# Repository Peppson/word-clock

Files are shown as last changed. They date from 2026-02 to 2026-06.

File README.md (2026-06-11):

# WordClock   

> **Note:** This is a personal hobby project.  

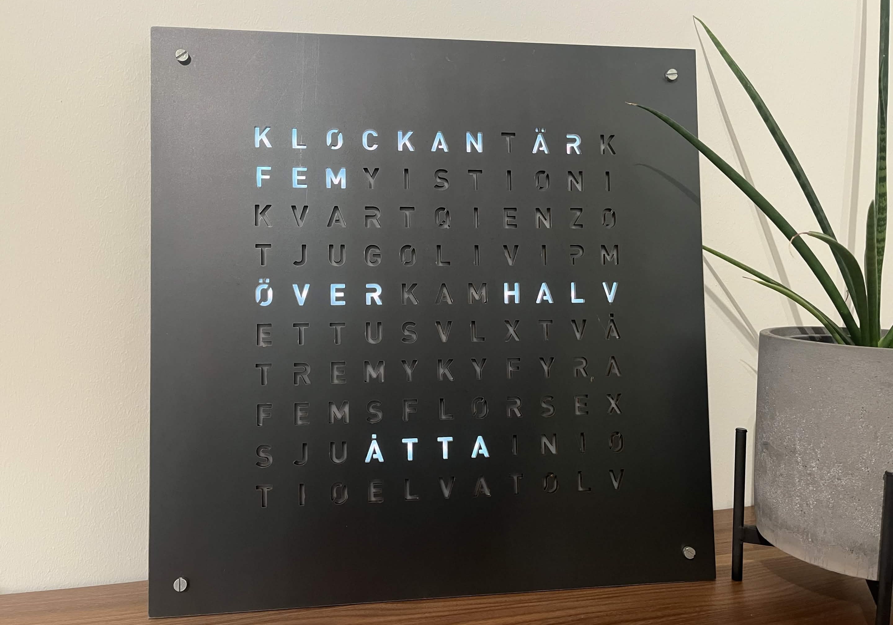
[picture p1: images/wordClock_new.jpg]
wordClock
 

## Overview
- Machine-cut 45x45cm metal faceplate *(Swedish time notation)*
- Web Interface for configuration and playing games on the 11x10 grid! 
- Wi-Fi time synchronization with optional manual time setting
- Ambient light sensor for automatic brightness control
- Physical buttons for direct control
- NeoPixel LEDs with full RGB color

## Web Interface
A simple accesspoint that is activated using a physical button.
- Configure Wi-Fi credentials for NTP time synchronization
- Manually set the time *(alternative to NTP)*
- Adjust LED colors
- Play Snake *(why not?)*

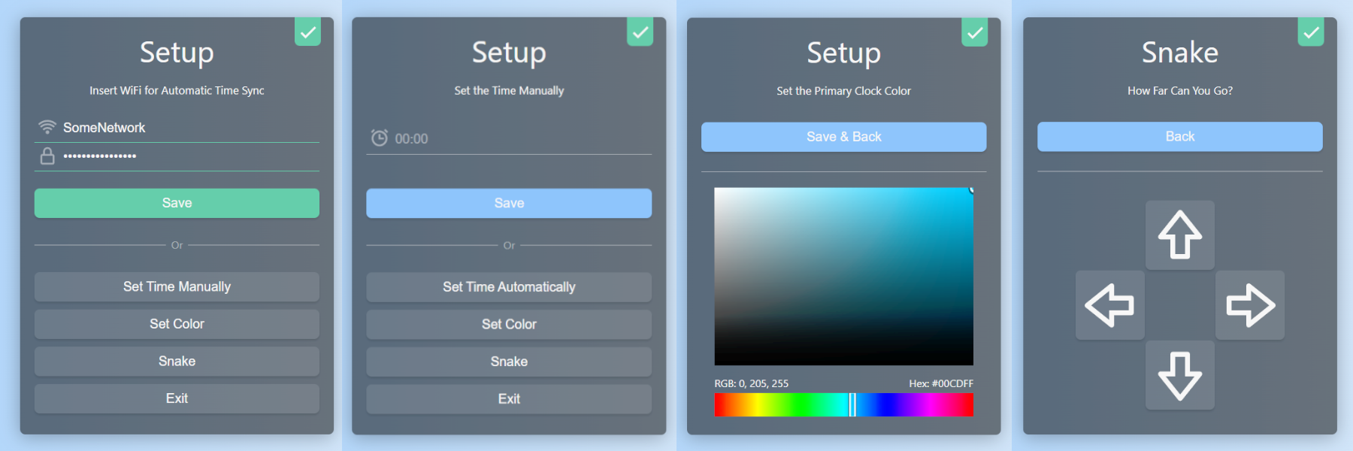
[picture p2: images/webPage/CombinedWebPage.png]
webPage
 

## Hardware/Build

#### Parts used:
- ESP32 microcontroller
- WS2812B (NeoPixel) LEDs ×110
- TSL2591 lux sensor
- Basic electronic components

Schematic:
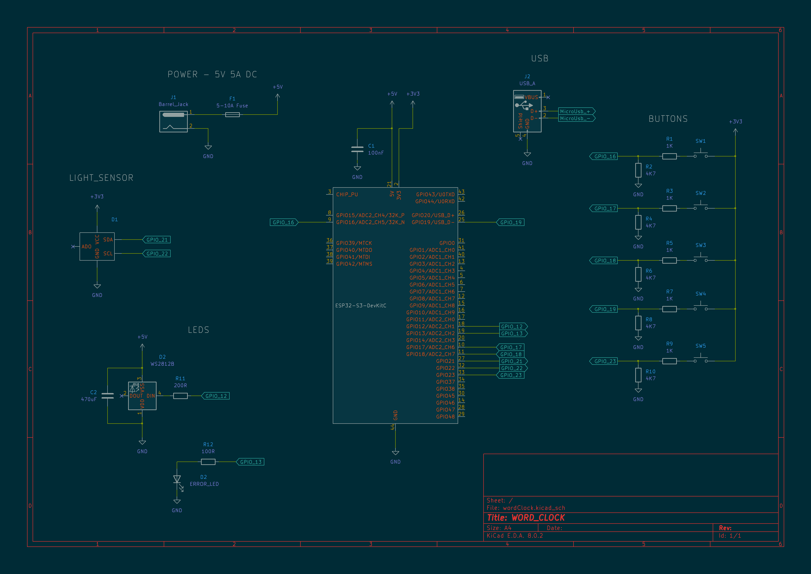
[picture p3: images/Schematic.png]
Schematic
 

Cross section *(thanks Chat)*
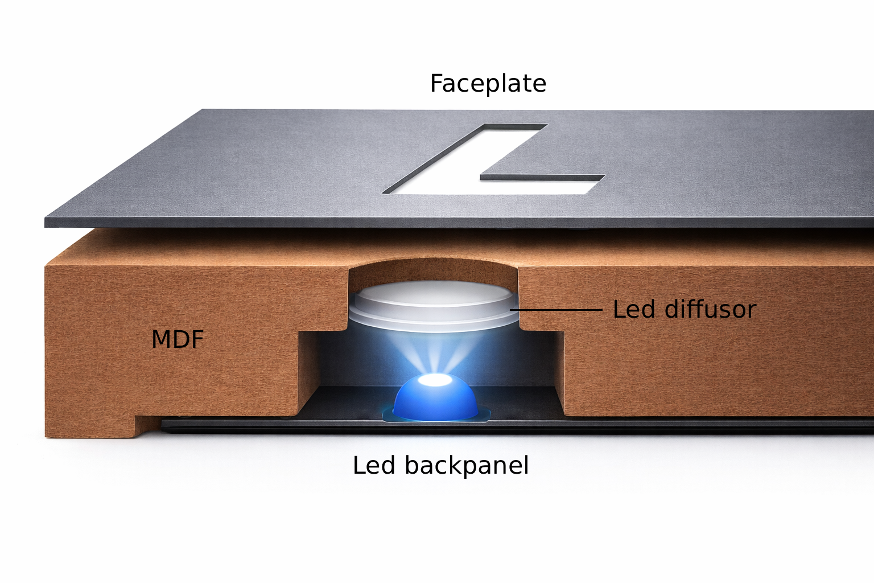
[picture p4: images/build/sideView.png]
 

MDF backside:
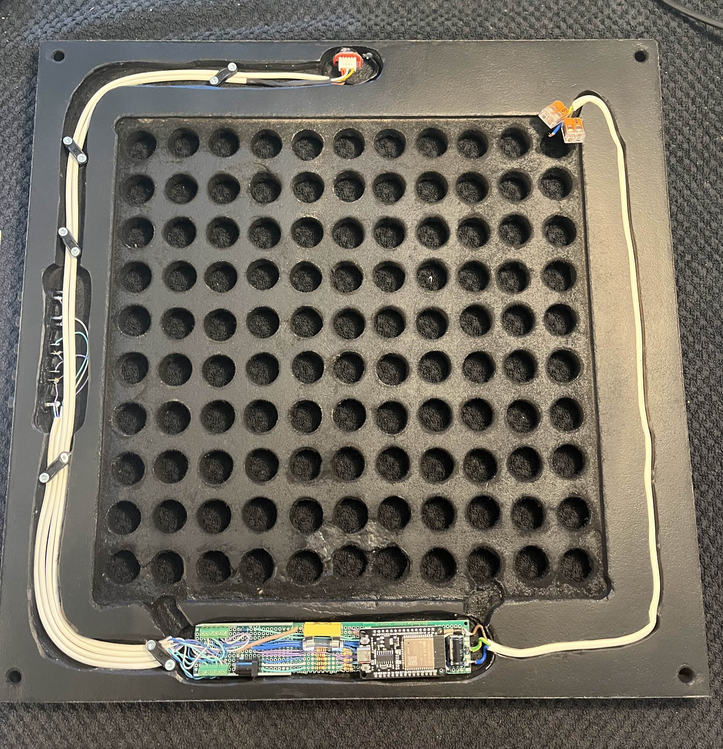
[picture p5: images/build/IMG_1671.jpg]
build
 

LED panel:  
*Lesson learned. Check LED strip spacing first. Ended up soldering every LED individually...*
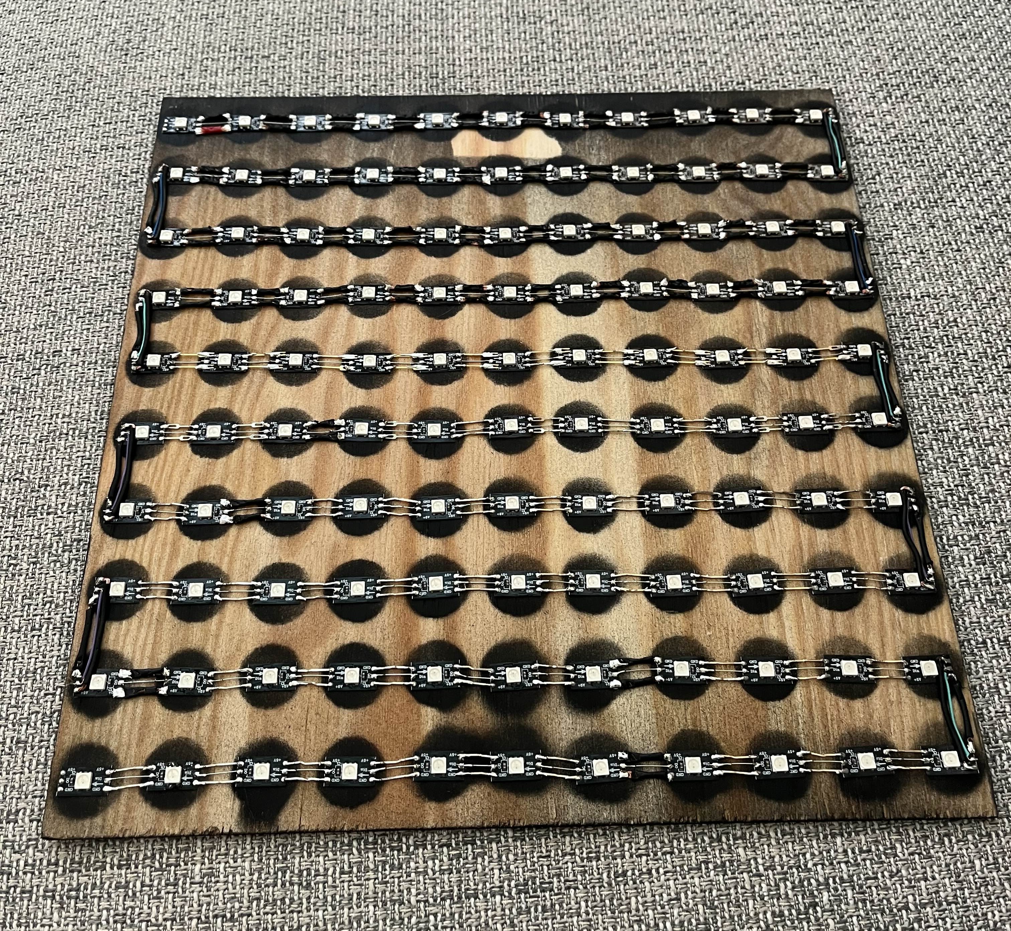
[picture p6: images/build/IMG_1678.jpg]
build
 

LED diffusors:  
*Simple frosted plastic sheet cut into circles.*
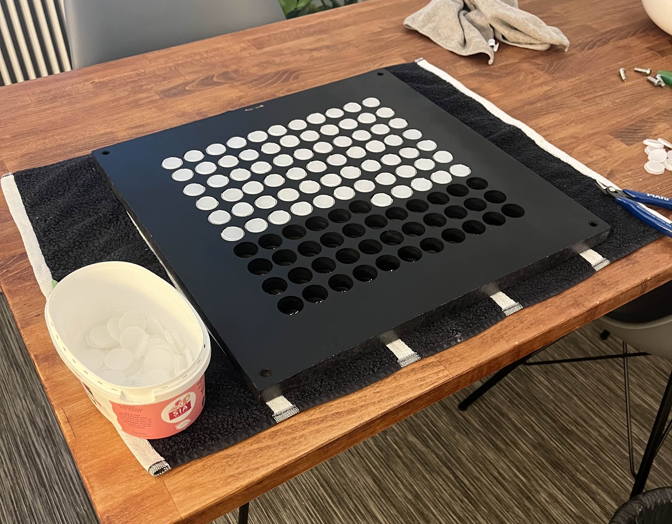
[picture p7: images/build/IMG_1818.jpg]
build
 

<details open>
    <summary>More build images</summary>

<br>

Top: light sensor + status LED
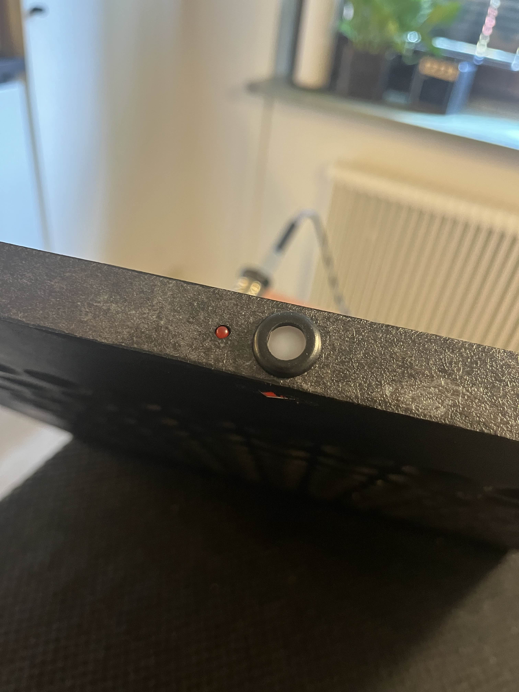
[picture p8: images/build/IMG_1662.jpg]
build
   

Right side: Buttons
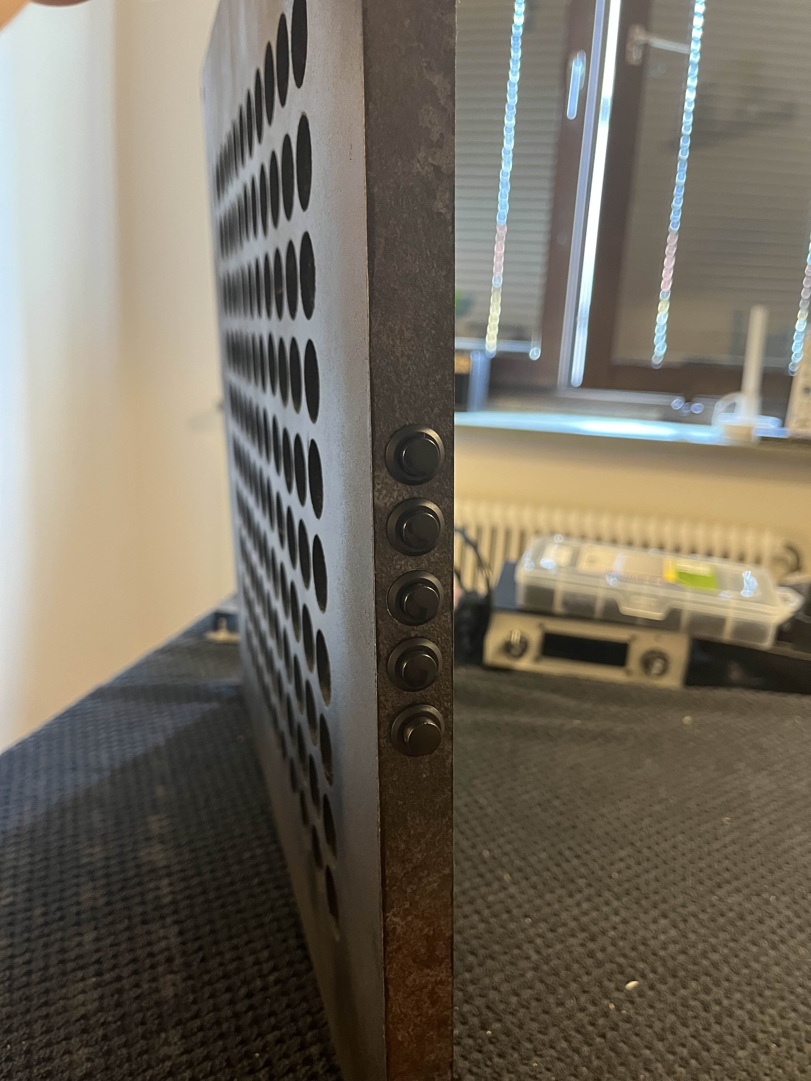
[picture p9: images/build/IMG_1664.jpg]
build
   

Without LED diffusors
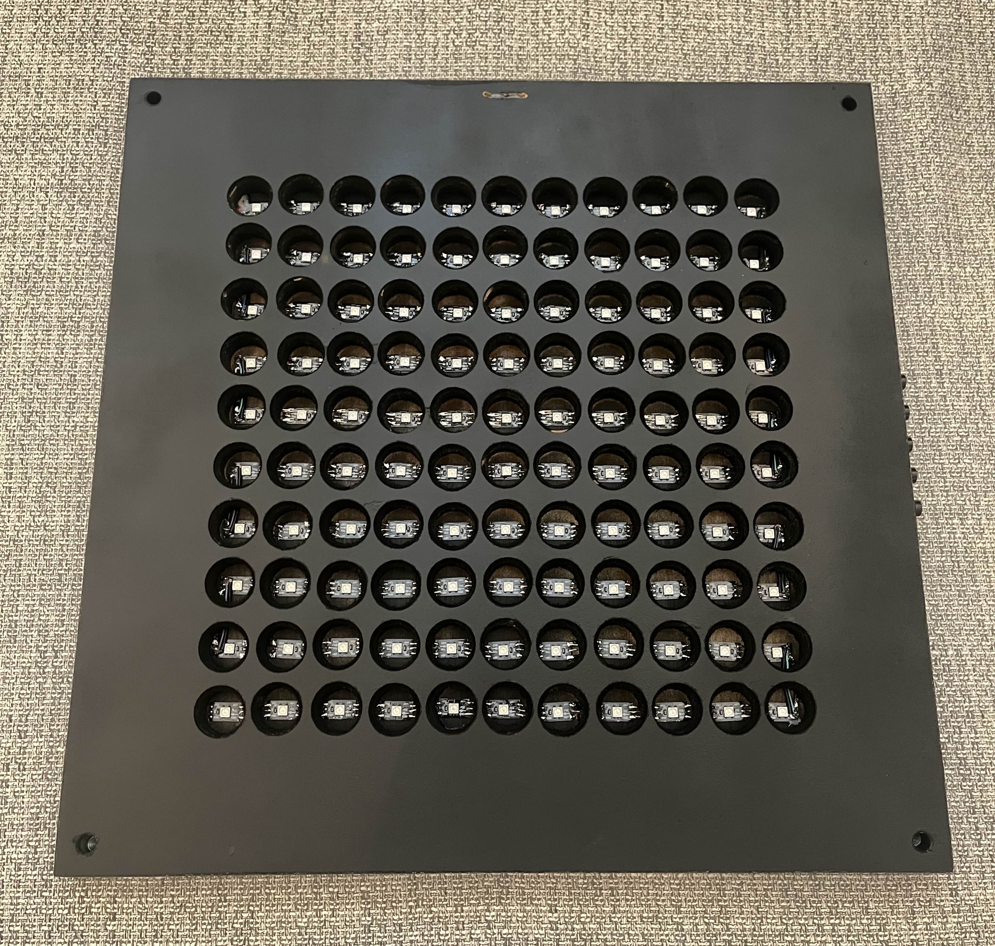
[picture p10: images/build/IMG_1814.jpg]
build
   

With LED diffusors
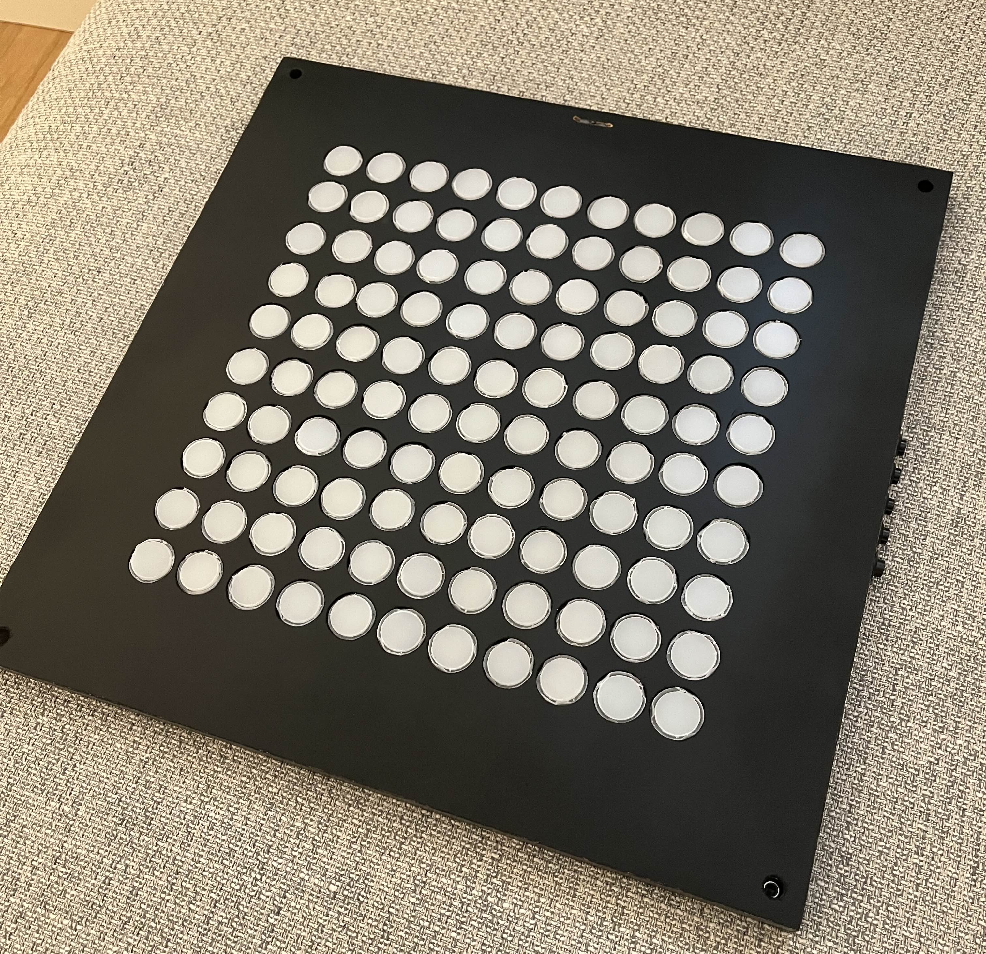
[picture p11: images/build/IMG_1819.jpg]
build
 

Backside with LED panel
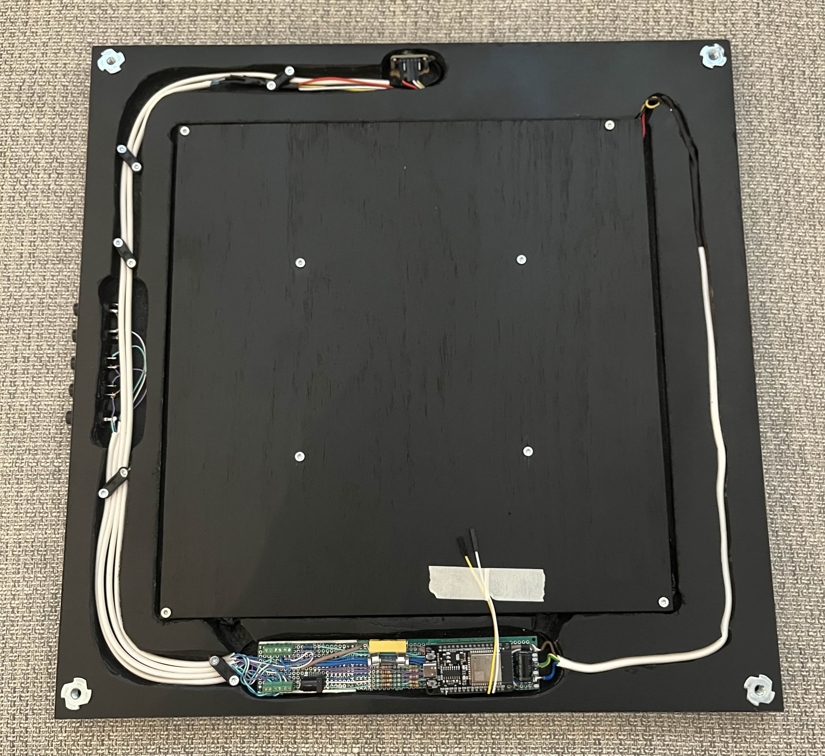
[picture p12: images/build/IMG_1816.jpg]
build
 
 
</details>

<br>

## LEDs brightness correction

Brightness is mapped through a custom correction curve to better match perceived light levels from the lux sensor.  
It took some trial and error to calibrate, but this curve works well for the current placement of the clock.  
In total darkness, the LEDs are turned off.  

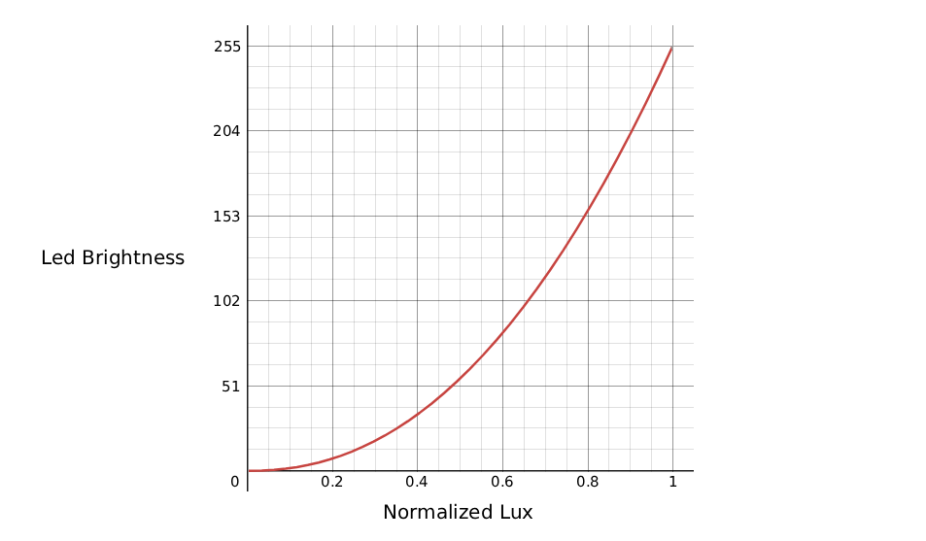
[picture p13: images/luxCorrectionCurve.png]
curve
 

Example code:
```c++
float normalizedAverage = luxAverage / LUX_THRESHOLD_MAX;
float mappedAverage = applyCorrectionCurve(normalizedAverage);
float scaledAverage = scaleLedBrightness(mappedAverage); // Hardware btn scaler in 0.2f steps
```

More images in [📂 images/](./images/)

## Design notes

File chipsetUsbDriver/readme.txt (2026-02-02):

CH340 USB driver from:

https://learn.sparkfun.com/tutorials/how-to-install-ch340-drivers/all

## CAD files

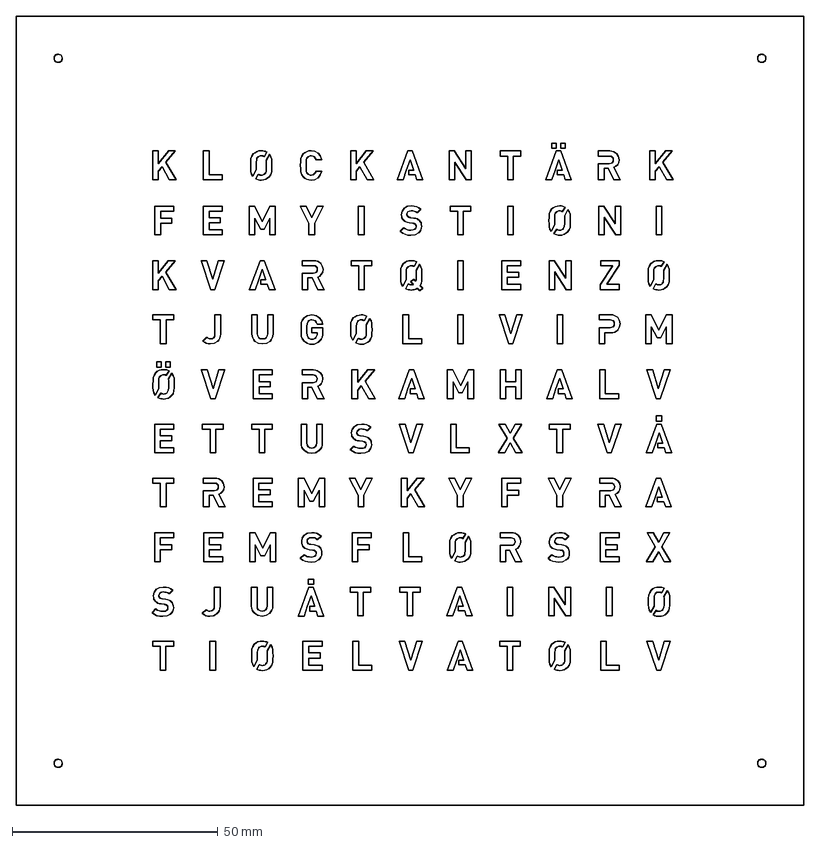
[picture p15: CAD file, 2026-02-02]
faceplate/45x45_CAD_R14.dxf
191.5 x 191.8 mm

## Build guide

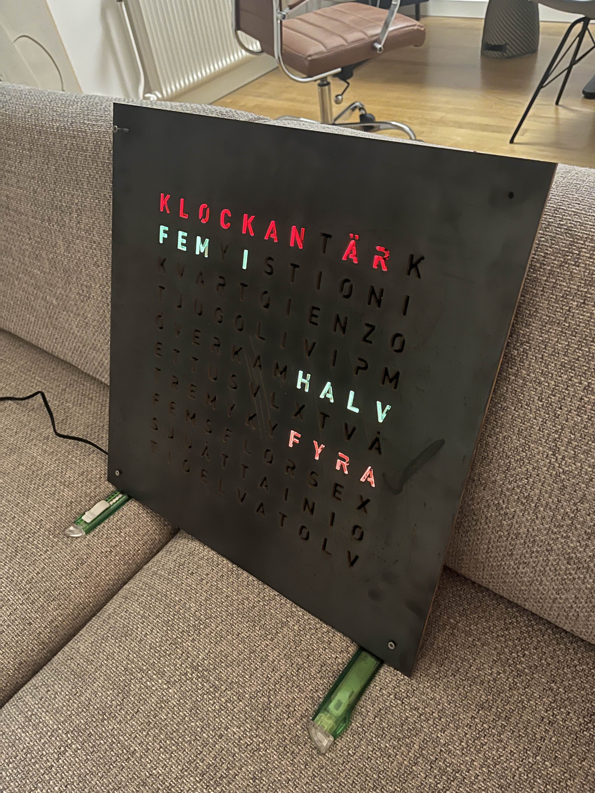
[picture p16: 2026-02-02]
images/build/IMG_1687.jpg

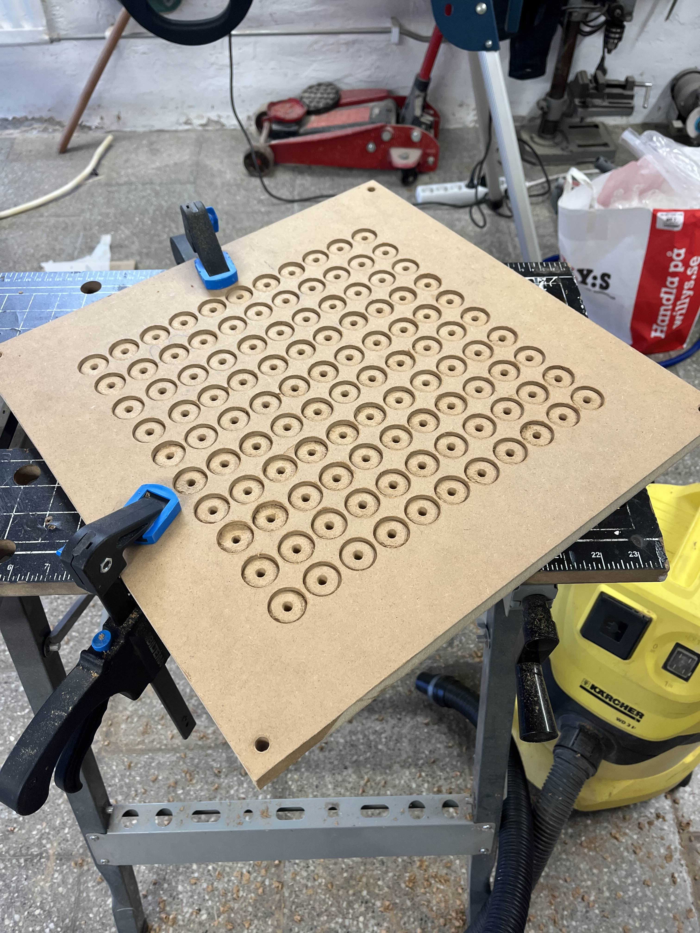
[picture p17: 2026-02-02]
images/build/IMG_1512.jpg

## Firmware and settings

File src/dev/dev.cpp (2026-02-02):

/* #include <Arduino.h>
#include <Wire.h>
#include "dev.hpp"


void setup()
{
	initSerial();
	Serial.println("\n\n\nI2C Scanner starting...");

	// printf("\n#####  Stop right there criminal scum!  ##### \n"); while (1) { delay(1); }
	delay(100);

	bool wireSuccess = Wire.begin();
	Serial.println(wireSuccess ? "Wire initialized successfully." : "Failed to initialize Wire.");
}

void loop()
{
	byte error, address;
	int devicesFound = 0;

	Serial.println("Scanning I2C bus...");

	for (address = 1; address < 127; address++)
	{
		Wire.beginTransmission(address);
		error = Wire.endTransmission();

		if (error == 0)
		{
			Serial.print("I2C device found at address 0x");
			if (address < 16)
				Serial.print("0");
			Serial.print(address, HEX);
			Serial.println(" !");
			devicesFound++;
		}
	}

	if (devicesFound == 0)
		Serial.println("No I2C devices found\n");

	delay(2000); // Wait 2 seconds before next scan
} */

#include <Wire.h>
#include <Adafruit_Sensor.h>
#include "Adafruit_TSL2591.h"
#include "dev.hpp"
#include "FS.h"
#include "SPIFFS.h"
#include <cstdio>

float minLux = MAXFLOAT;
float maxLux = -MAXFLOAT;
const char *luxFile = "/lux.txt";
Adafruit_TSL2591 tsl = Adafruit_TSL2591(1);
void loadLuxValues();
void initSensor();
void resetLuxValues();

void setup()
{
	initSerial();

	if (!SPIFFS.begin(true))
	{
		Serial.println(F("SPIFFS Mount Failed"));
		return;
	}

#if 0
	resetLuxValues();
	log("Values reset!\n");
	loadLuxValues();
	while (1)
	{
	}
#endif

	loadLuxValues();
	delay(10000);
	initSensor();
}

void initSensor()
{
	tsl.setGain(TSL2591_GAIN_HIGH);				  // Mid/High?
	tsl.setTiming(TSL2591_INTEGRATIONTIME_200MS); // tsl.setTiming(TSL2591_INTEGRATIONTIME_200MS);

	if (tsl.begin())
		Serial.println(F("Found a TSL2591 sensor"));
	else
	{
		Serial.println(F("No sensor found ... check your wiring?"));
		while (1)
			;
	}
}

void saveLuxValues()
{
	File file = SPIFFS.open(luxFile, FILE_WRITE);
	if (!file)
	{
		Serial.println(F("Failed to open file for writing"));
		return;
	}

	file.printf("%.2f %.2f\n", minLux, maxLux);
	file.close();
	Serial.println(F("Lux min/max saved"));
}

void loadLuxValues()
{
	if (!SPIFFS.exists(luxFile))
	{
		Serial.println(F("No previous lux data"));
		return;
	}
	File file = SPIFFS.open(luxFile, FILE_READ);
	if (!file)
	{
		Serial.println(F("Failed to open file for reading"));
		return;
	}

	String content = file.readStringUntil('\n');
	file.close();

	if (sscanf(content.c_str(), "%f %f", &minLux, &maxLux) == 2)
	{
		Serial.printf("Loaded minLux=%.2f maxLux=%.2f\n", minLux, maxLux);
	}
	else
	{
		Serial.println(F("Failed to parse lux data"));
	}
}

void resetLuxValues()
{
	minLux = MAXFLOAT;
	maxLux = -MAXFLOAT;

	if (SPIFFS.exists(luxFile))
	{
		SPIFFS.remove(luxFile);
		Serial.println(F("Lux file deleted, values reset"));
	}
	else
	{
		Serial.println(F("No lux file found, values reset in memory"));
	}
}

void getLuxLevel()
{
	sensors_event_t event;
	tsl.getEvent(&event);

	if ((event.light == 0) || (event.light > 4294966000.0) || (event.light < -4294966000.0))
	{
		Serial.println(F("Invalid data (adjust gain or timing)"));
		return;
	}
	else
	{
		Serial.print(event.light);
		Serial.println(F(" lux"));
	}

	float lux = event.light;
	Serial.printf("Lux: %.2f\n", lux);

	bool updated = false;
	if (lux < minLux)
	{
		minLux = lux;
		updated = true;
	}
	if (lux > maxLux)
	{
		maxLux = lux;
		updated = true;
	}

	if (updated)
	{
		Serial.printf("Updated min=%.2f max=%.2f\n", minLux, maxLux);
		saveLuxValues();
	}
}

void loop()
{
	getLuxLevel();
	delay(2000);
}

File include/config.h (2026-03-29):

#pragma once
#include <Arduino.h>
#include <stdio.h>
#include <FastLED.h>
#include "utility.h"

// Dev
#define PRINT_ENABLED 0                                 // Print over serial connection 
#define PRINT_SNAKE_ENABLED 0                           // Print snake game inputs
#define PRINT_SYSTEM_TIME 0                             // Print system time each second
#define DEBUG_RESET_ALL 0                               // Full reset
#define DEBUG_ACCESSPOINT 0                             // Boot with AP
#define DEBUG_IGNORE_CLOCK_SOURCE 0                     // Boot with clock soruce = NONE
#define DEBUG_SNAKE 0                                   // Boot with snake   
#define DEBUG_OVERRIDE_BRIGHTNESS 0                     // Set static brightness level uint8. > 0 (Sensor disabled)
#define DEBUG_TEST_FULL_BRIGHTNESS 0                    // For measuring max current consumption
#define USE_SECRET_CREDENTIALS 1                        // Use WiFi credentials from secret.h instead of memory
#define USE_KEYBOARD 0                                  // Serial (USB keyboard) added as buttons
#define FRIEND_CLOCK 0                                  // Different startup animation, nsfw...
#define SERPENTINE_LED_LAYOUT 1                         // See below

/*
*   ######### Led layout #########  
*
*   SERPENTINE_LED_LAYOUT true
*   0  >  1  >  2  >  3  >  4 ... 11
*                                 |
*   22 ... 15  <  14  <  13  <  12
*   |
*   23...
*
*   SERPENTINE_LED_LAYOUT false
*   0  >  1  >  2  >  3  >  4 ... 11
*   12  >  13  >  14  >  15...
*/

constexpr const char* AP_SSID = "Clock-Setup";          // Device name
constexpr const char* NTP_SERVER = "pool.ntp.org";      // NTP server
constexpr const char* MEMORY_LOCATION = "Memory";       // Identifier string
constexpr int GMT_OFFSET_SEC = 3600;                    // GMT +- in seconds                        (Hardcoded for Sweden)
constexpr int DAY_LIGHT_OFFSET_SEC = 3600;              // Daylight saving?                         (Hardcoded for Sweden)
constexpr uint WIFI_CREDENTIALS_MAX_LENGTH = 30;        // Max length for ssid and password  
constexpr uint JSON_PAYLOAD_MAX_LENGTH = 200;           // Max payload length           
constexpr uint ACCESSPOINT_UPTIME = 10*60*1000;         // Accesspoint upactive
constexpr uint BUTTON_DEBOUNCE_INTERVAL = 250;          // Debounce delay in ms for buttons
constexpr uint SNAKE_GAME_SPEED = 250;                  // Delay in ms between "frames" (ms = 1000/fps)
constexpr uint SERIAL_BAUD_RATE = 115200;               // Baud TX/RX
constexpr const char* HTML_FILE_PATHS[] = {             // Webpages in /data
    "/webpage.txt", 
    "/webpageBackup.txt"
};

// Lux sensor
constexpr uint8_t LUX_READINGS_SIZE = 4;                // Size of average, essentially the speed of change
constexpr float LUX_THRESHOLD_MAX = 10;                 // Light sensor threshold for max brightness
constexpr float LUX_CURVE_EXPONENT = 2.2f;              // Brightness correction: (normalized luxLevel)^x
constexpr uint LED_MIN_BRIGHTNESS = 5;                  // Min led brightness

// Leds
constexpr bool LEDS_OFF_IN_TOTAL_DARKNESS = true;       // Turn off all leds in total darkness
constexpr float LED_INITIAL_SCALER = 0.4f;              // Boot ledscaler
constexpr uint DEFAULT_CLOCK_COLOR = 0xFFB936;          // Main Color
constexpr uint DEBUG_CLOCK_COLOR = 0xFF4500;            // Debug
constexpr uint16_t MATRIX_WIDTH = 11;                   // Wordclock led width
constexpr uint16_t MATRIX_HEIGHT = 10;                  // Wordclock led height

// Physical I/O
constexpr uint8_t BTN_ACCESSPOINT = 19;                 // Old 16
constexpr uint8_t BTN_RESET = 23;                       // Old 17
constexpr uint8_t BTN_HOUR = 18;                        // Old 18
constexpr uint8_t BTN_5_MINUTES = 16;                   // Old 19
constexpr uint8_t BTN_BRIGHTNESS = 17;                  // Old 23
constexpr uint8_t PIN_ERROR_LED = 13;
constexpr uint8_t PIN_LED_DATA = 12;

// Global enums
enum FadeType : bool
{
    FADE_IN = true,
    FADE_OUT = false
};

enum ClockSource : uint8_t 
{ 
    NONE, 
    TIME_INPUT, 
    WIFI 
};

enum DebugPrintType 
{
    WIFI_FORM,
    TIME_FORM,
    MEMORY_WIFI,
    MEMORY_TIME,
    MEMORY_SOURCE,
};

// Print toggle
#if PRINT_ENABLED
    #define log(...) printf(__VA_ARGS__)
    #define PRINT_INFO(...) utils::debugPrintInfo(__VA_ARGS__)
    #define STOP printf("\n#####  Stop right there criminal scum!  ##### \n"); while (1) { delay(1); }
#else
    #define log(...)
    #define PRINT_INFO(...)
    #define STOP while (1) { delay(1); }
#endif

#if PRINT_SNAKE_ENABLED
    #define PRINT_BTN(...) printf(__VA_ARGS__)
#else 
    #define PRINT_BTN(...)
#endif
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

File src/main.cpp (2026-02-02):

#include "config.h"
#include "core/storage.h"
#include "core/timeKeeper.h"
#include "core/lightSensor.h"
#include "core/neoPixels.h"
#include "core/hardware.h"

NeoPixels pixel;
Hardware hardware;
TimeKeeper chrono(&pixel);

void setup()
{
    Storage storage(true);
    hardware.setup(&pixel);
    pixel.setCurrentColorOnBoot(storage);
    pixel.animation_startup();
    pixel.setLedBrightnessOnBoot();

    #if defined(ANY_DEBUG_SYMBOL)
        utils::initDebugging(&storage, &hardware, &pixel, &chrono);
    #endif

    ///@note Clock source could be either:
    // 1. No time is set. Time starts at 0
    // 2. Manual time set. Update time accordingly (set from AP)
    // 3. WiFi credentials set. Sync time through NTP server (set from AP)
    hardware.setClockFromSource(storage, chrono);
    hardware.enableInterrupts();
}

void loop()
{
    if (Hardware::buttonAccesspoint)
        hardware.beginAccesspoint();

    if (Hardware::buttonReset)
        hardware.resetBtnPressed();

    if (chrono.clockSource == ClockSource::WIFI)
        chrono.syncSystemTimeAtNight();

    // Set led brightness based on ambient light + brightness button scaling
    pixel.updateLedBrightness(chrono);
    chrono.getSystemTime();
    pixel.renderClock(&chrono.timeinfo, chrono.offsetHours, chrono.offsetMinutes);

    // Boeing is jealous
    hardware.timerOverflowHandler(chrono);

    #if USE_KEYBOARD
        hardware.debugKeyboardInput(chrono);
    #endif
    #if PRINT_SYSTEM_TIME
        utils::printSystemTime(chrono);
    #endif
}

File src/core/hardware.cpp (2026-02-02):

#include "core/hardware.h"
#include "core/accesspoint.h"
#include "core/storage.h"
#include "core/timeKeeper.h"
#include "core/lightSensor.h"

// Static members
volatile bool Hardware::buttonReset = false;
volatile bool Hardware::buttonAccesspoint = false;
volatile bool Hardware::timeSetBybutton = false;
volatile bool Hardware::brightnessSetBybutton = false;
NeoPixels* Hardware::pixel;


void Hardware::setup(NeoPixels* px) 
{
    // Init I/O buttons with internal + external 4K7 pulldown R
    pinMode(BTN_HOUR, INPUT_PULLDOWN);
    pinMode(BTN_5_MINUTES, INPUT_PULLDOWN);
    pinMode(BTN_BRIGHTNESS, INPUT_PULLDOWN);
    pinMode(BTN_ACCESSPOINT, INPUT_PULLDOWN);
    pinMode(BTN_RESET, INPUT_PULLDOWN);

    // Led
    pinMode(PIN_ERROR_LED, OUTPUT);
    digitalWrite(PIN_ERROR_LED, LOW);

    #if PRINT_ENABLED
        beginSerial();
    #endif

    pixel = px;
    px->setup();
    px->setupLightSensor();
    printDebugInfo(px);
}

void Hardware::setClockFromSource(Storage& storage, TimeKeeper& chrono) 
{
    #if DEBUG_IGNORE_CLOCK_SOURCE
        TimeKeeper::clockSource = ClockSource::NONE;
        log("\n------- DEBUG_IGNORE_CLOCK_SOURCE -------\nClock source = NONE\n");
        return;
    #endif

    Preferences memory;
    memory.begin(MEMORY_LOCATION);
    
    uint8_t clockSource = storage.getClockSource(memory);
    bool success = true;
    
    if (clockSource == ClockSource::TIME_INPUT) 
        success = setClockFromTimeInput(storage, chrono, memory);
    else if (clockSource == ClockSource::WIFI) 
        success = setClockFromWiFiInput(storage, chrono, memory);
    else if (clockSource == ClockSource::NONE)
        chrono.resetSystemTime();

    if (success) 
    {
        TimeKeeper::clockSource = clockSource;
        chrono.printSystemTime();
    } 
    else 
    {
        TimeKeeper::clockSource = ClockSource::NONE;
        log("Error reading clock source! Reverting clock source to \"NONE\" \n");
        storage.setClockSource(memory);
    }

    memory.end();
}

bool Hardware::setClockFromTimeInput(Storage& storage, TimeKeeper& chrono, Preferences& memory) 
{
    if (!storage.getTimeInput(memory))       return false; 
    if (!chrono.setSystemTime())                    return false;
    if (!storage.setClockSource(memory))    return false;

    return true;
}

bool Hardware::setClockFromWiFiInput(Storage& storage, TimeKeeper& chrono, Preferences& memory) 
{
    if (!storage.getWiFiCredentials(memory)) return false;  
       
    // Try sync time via NTP server 
    chrono.syncSystemTimeWiFi(&storage, true);
    return true;
}

void Hardware::beginAccesspoint()
{
    disableInterrupts();
    AccessPoint accesspoint(pixel);
    accesspoint.setup();
    pixel->animation_fadeAll(FADE_OUT); 
    enableAccesspointInterrupt();

    // Loops here until manual exit or after ACCESSPOINT_UPTIME
    accesspoint.loop();

    // Restart device
    disableAccesspointInterrupt();
    delay(1000);
    accesspoint.~AccessPoint();
    reboot();
}

void Hardware::reboot() 
{
    // Makes sure the fadeout begins at whatever brightness was before,
    // if rebooting from accesspoint
    if (AccessPoint::isActive) 
    {
        pixel->ledBrightness = pixel->animationLedBrightness;
    }

    pixel->animation_fadeAll(FADE_OUT);
    delay(500);
    ESP.restart();
}

void Hardware::timerOverflowHandler(TimeKeeper& chrono) 
{
    constexpr uint32_t threshold = (UINT32_MAX - 1) - (24*60*60*1000UL);

    // Timestamp in mS from device boot, overflows every ~ 50 days.
    // Rough solution, just restart the device when near the threshold ¯\_(ツ)_/¯
    if (millis() < threshold) return; 

    // Save the current time to mem, for retreval after reboot
    // Skip if clock source = WiFi
    if (chrono.clockSource != ClockSource::WIFI) 
    {
        Storage storage(true);

        chrono.getSystemTime();
        uint8_t hour = (chrono.timeinfo.tm_hour + chrono.offsetHours) % 24;
        uint8_t minute = (chrono.timeinfo.tm_min + chrono.offsetMinutes) % 60;

        char current_time[6];
        sprintf(current_time, "%02d:%02d", hour, minute);

        if (storage.validateTimeInput(current_time)) 
        {
            storage.setTimeInput(current_time);
        }
    }

    log("millis() overflow in 24h, rebooting...\n");
    reboot();
}

void Hardware::beginSerial() 
{
    Serial.begin(SERIAL_BAUD_RATE);
    while (!Serial && millis() < 3*1000) { }

    delay(50);
    log("\n\n\n\n\n----------- STARTED -----------\n");
}

void Hardware::errorLED(bool error) 
{   
    if (error)
    {
        log("----------- Error -----------\n"); // Great logging :)
        digitalWrite(PIN_ERROR_LED, HIGH);
    }
    else 
    {
        digitalWrite(PIN_ERROR_LED, LOW);
    }
}
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
